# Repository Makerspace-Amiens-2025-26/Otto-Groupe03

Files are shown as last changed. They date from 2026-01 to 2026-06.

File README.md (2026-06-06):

# BMW-OTTO BOT

Template pour la création d'un repo type projet pour le MakerSpace. Doc gérée via le thème [Just-The-Docs](https://just-the-docs.com) en vanilla.

## Bienvenue sur Notre Projet

Ce repository est le cœur de notre projet. Ici, vous trouverez toutes les ressources nécessaires pour comprendre, utiliser et contribuer à notre projet.

### Contenu du Repository

- **Documentation :** Toutes les documentations techniques et guides d'utilisation sont disponibles dans le dossier `docs`. Voir le site de doc associé. 
- **project :** Toutes les sources de notre projet.

### Comment Utiliser ce Repository ?

- Pour commencer, consultez la documentation dans le dossier `docs`.
- Si vous souhaitez contribuer au projet, veuillez lire nos directives de contribution.

## Contribution

Nous accueillons et apprécions toute contribution. Si vous souhaitez contribuer, veuillez consulter notre guide de contribution pour connaître nos attentes et notre processus.

## Contact

Si vous avez des questions ou des suggestions, n'hésitez pas à nous contacter.

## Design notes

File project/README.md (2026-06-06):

# Les ressources du projet
Vous retrouverez les fichiers STL pour imprimer toutes les pièces nécessaires à la réalisation du robot

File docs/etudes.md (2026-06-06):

---
layout: default
nav_order: 4
title: Études et choix techniques
---

# Études et choix techniques

**CHÂSSIS**:

Pour aborder efficacement les différentes épreuves des Ottolympiades, on a dû faire des choix stratégiques. Il ne s'agissait pas seulement de donner un look "sport" à notre robot, mais d'utiliser l'univers mécanique de BMW pour optimiser ses performances réelles sur la piste.

Le design de notre OTTO-BMW a été pensé pour répondre aux contraintes physiques des épreuves de force et de vitesse :

* Abaissement du centre de gravité (Pour le Sumo) : Pour éviter que notre robot ne bascule facilement lors des duels sur le ring, nous avons choisi de placer la batterie le plus bas possible dans le corps du robot. De plus, nous avons augmenté le taux de remplissage des pieds afin d'alourdir la base et d'améliorer la stabilité.

* Adhérence des pneumatiques (Pour le Tir à la corde) : Les pieds en plastique PLA lisse d'origine glissaient sur la piste. En étudiant les solutions, nous avons décidé d'ajouter du papier de verre (découpée dans une chambre à air) sous les pieds du robot. Ce choix technique mime l'adhérence des pieds d'une vraie sportive et augmente notre force de traction de manière significative.

* L'Aileron M Performance (Utilité technique) : Au-delà du look, l'aileron arrière a été conçu avec un angle d'inclinaison spécifique pour servir de point d'ancrage solide et centré pour la corde lors de l'épreuve du Tir à la corde, évitant ainsi de désaxer le robot pendant l'effort.

**MOTORISATION** : 

Bien que la carte mère OTTO-MKS (ESP32-C3) soit imposée, nous avons optimisé l'utilisation des périphériques :

* Gestion des Servomoteurs SG90 : Ces moteurs fonctionnent avec des signaux PWM pour contrôler leur angle (0 à 180°). Pour la course de vitesse (Chrono Challenge), nous avons étudié les limites physiques des moteurs afin de trouver la fréquence maximale de balancement des jambes sans faire surchauffer les composants ni faire patiner le robot.

* Le Capteur Ultrason HC-SR04 (Les "Phares") : Intégré esthétiquement comme des optiques de phares BMW, ce capteur calcule la distance en mesurant le temps de retour d'une onde ultrason. Nous l'avons configuré pour deux fonctions clés : stopper le robot à 15 cm d'un mur (Course d'obstacles) et détecter la présence de l'adversaire à moins de 25 cm pour foncer dessus (Mode Sumo).

**LOGICIELS ET STRATEGIES** :

Le comportement du robot a été programmé sous l'IDE Arduino. Nous avons créé une véritable "cartographie moteur" adaptée à chaque épreuve :

* Le Mode "Sport" (Vitesse) : Pour le Chrono Challenge, nous avons développé une fonction de marche avec de grandes amplitudes de pas (angles des servos poussés au maximum) et un timing très court entre chaque pas pour obtenir une vitesse en ligne droite maximale.

* Pour le tir à la corde, nous avons programmé une fonction de marche arrière mais avec de petites amplitudes de pas pour que le robot soit le plus stable possible.

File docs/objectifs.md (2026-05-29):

---
layout: default
nav_order: 3
title: Objectifs du projet
---

# Introduction

Le projet OTTO-MKS, c'est le tout premier projet de robotique des premières années d'ingénieur à UniLaSalle Amiens.

Le but est simple : fabriquer et programmer un petit robot humanoïde en équipe. Nous sommes partis d'un modèle open-source ultra-connu (le robot Otto DIY), et le MakerSpace de l'école l'a amélioré pour créer l'OTTO-MKS, une version plus puissante connectée en Bluetooth et Wi-Fi.

Ce projet nous permet d'apprendre les bases du métier d'ingénieur :

* Mécanique : Modéliser et imprimer des pièces en 3D.

* Électronique : Connecter les moteurs et les capteurs.

* Programmation : Coder les mouvements et l'intelligence du robot.

Le point culminant du projet ? Les Ottolympiades ! Un grand tournoi où nos robots s'affrontent lors de la Journée des Projets dans des épreuves de course, de sumo et de tir à la corde.

Ce document présente notre travail, nos choix techniques et notre robot final pour la compétition.

## Contexte du Projet

Le projet OTTO-MKS est une version sur mesure ("made in UniLaSalle Amiens") du célèbre robot humanoïde open-source Otto DIY. Le robot original a été créé à l'origine pour enseigner les bases de la robotique, des STEM (Sciences, Technologie, Ingénierie, Mathématiques) et de la programmation.

Le MakerSpace d'Amiens a repris ce concept open-source pour l'adapter aux besoins spécifiques de ses étudiants et pour en faire le tout premier projet d'ingénierie des étudiants de première année. Pour cela, l'équipe du MakerSpace a conçu une version améliorée du robot :

* l'apprentissage par la pratique (Learning by doing), mêlant modélisation 3D (via OnShape), impression 3D des pièces mécaniques, assemblage de composants (servomoteurs, capteurs ultrason) et programmation (via l'IDE Arduino).

* Une carte électronique sur mesure (Otto-MKS) : Conçue au MakerSpace, elle intègre un microcontrôleur performant (ESP32-C3) offrant des capacités de communication sans fil (Bluetooth et Wi-Fi) permettant par exemple de piloter le robot avec un smartphone.

## Objectifs du Projet

Les objectifs du projet OTTO-MKS s'articulent autour de trois grands axes : pédagogique, technique et événementiel.

**Objectifs pédagogiques**:

On travaille par groupe de trois avec pour objectifs de :

* Découvrir la fabrication numérique : S'approprier les outils d'un MakerSpace, comprendre la modélisation 3D et gérer les contraintes de l'impression 3D.

* S'initier à la programmation embarquée : Programmer la logique du robot pour qu'il puisse marcher, détecter des obstacles et réagir à son environnement.

* Développer des compétences transversales : Travailler en équipe, documenter techniquement un projet (via un rapport ou un site web) et vulgariser leur travail à travers une vidéo de présentation professionnelle d'une minute.

**Objectifs techniques**:

* S'approprier et itérer : Au-delà du modèle de base fourni, l'objectif est de faire preuve de créativité. On doit modifier le code et le design du robot, y ajouter des fonctionnalités (bras articulés, écrans OLED, capteurs gyroscopiques, lumières).

* Fiabiliser et optimiser : Rendre le robot robuste mécaniquement et performant au niveau du code pour répondre à des contraintes physiques réelles.

* Améliorer ses compétences avec les logiciels et dans le code (Arduino)

**Objectifs événementiel**:

Le projet culmine chaque année lors de la Journée des Projets d'UniLaSalle Amiens, à travers un grand tournoi de robotique ludique et technique appelé les Ottolympiades (arbitré par l'association UniMakers). L'objectif ultime des étudiants est de préparer leur robot à valider l'homologation technique pour s'affronter dans 4 épreuves :

Chrono Challenge : Une course en ligne droite pour tester la vitesse pure.

Course d'obstacles : Un parcours d'agilité pour tester la détection de l'environnement.

Otto Sumo : Un duel sur un ring où le robot doit pousser son adversaire vers la sortie.

Tir à la corde : Une épreuve de force motrice par équipes de 3 robots.

# Existant

Notre projet s'appuie sur le robot bipède open-source Otto DIY, largement utilisé dans le domaine éducatif pour l'initiation aux STEM. Ce système existant est composé d'une structure imprimable en 3D, de 4 servomoteurs SG90 pour la locomotion, et d'un capteur ultrason HC-SR04 pour la détection d'obstacles.

Dans sa version standard, le contrôle est assuré par un microcontrôleur Arduino Nano. Bien que fonctionnelle pour un usage récréatif, cette configuration présente des limites techniques pour les objectifs des Ottolympiades : l'absence de connectivité sans fil native (Wi-Fi/Bluetooth) et la fragilité du câblage interne due à la superposition de cartes (Shield + Arduino).

C'est pour pallier ces limites que le MakerSpace d'UniLaSalle Amiens a développé la version OTTO-MKS, remplaçant cet existant par une carte électronique sur mesure intégrant une puce ESP32-C3.

# Cahier des Charges

**Dimensions**

Concernant les dimensions, Le robot devra faire au maximum :

* Largeur : 150 mm
* Longueur : 150 mm
* Hauteur : 200 mm

**Déplacement**

Pour les déplacements, le robot devra se déplacer en marchant.
L’interrupteur d’alimentation doit rester accessible en tout temps par l’arbitre afin d’arrêter le robot en cas de situation de danger pour lui-même, les autres robots, ou les éléments de jeu.

**Fabrication**

Le robot doit être fabriqué et programmé par les étudiant(e)s sans l’utilisation d’un kit du commerce. 
La modification est fortement encouragée mais ces derniers ne doivent pas pouvoir endommager le robot adverse. Les dispositifs présentant un danger sont évidemment proscrit.

**Mode de controle**

En fonction de l’épreuve, deux modes de fonctionnement pourront vous être demandés, précisés dans le règlement de l’épreuve :

* Mode autonome
Le robot doit être en mesure de réaliser l’épreuve sans aide extérieure ; il devra donc être programmé à l’avance pour jouer. Le signal de démarrage est propre à chaque épreuve et est spécifié dans son règlement.

* Mode télécommandé
Vous devrez programmer une solution de contrôle à distance, par exemple grâce à l’application RemoteXY.

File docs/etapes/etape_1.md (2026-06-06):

---
layout: default
title: Préparation des Matériaux
parent: Etapes de fabrication
nav_order: 1
---

# Préparation des Matériaux

Cette section décrit la première étape du processus de fabrication : la préparation des matériaux.

## Liste des Matériaux

- L'ensemble du dossier STL imprimé en 3d (PLA)
- Un set de tournevisse
- Du papier de verre + gros grain possible

## Procédure de Préparation

1. **Nettoyage** : Nettoyez les impressions enn retirant les supports et bavure
2. **Découpe** : Découpez le papier de verre a la taile des pieds en laissant une bande vide de 1cm a l'edxterieur du pied

## Conseils de Sécurité

- Portez toujours l'équipement de protection individuelle.
- Suivez les instructions de sécurité des outils utilisés.

---

Une fois cette étape terminée, passez à l'[Assemblage](/assemblage).

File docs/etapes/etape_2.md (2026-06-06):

---
layout: default
title: Assemblage
parent: Etapes de fabrication
nav_order: 2
---

# Assemblage

Après l’impression des pièces en 3D, l’étape suivante est l’assemblage du robot Otto.  
Cette étape permet de monter les servomoteurs, les jambes, les pieds, la tête, la carte électronique, le capteur ultrason et la batterie.

Schéma général du robot Otto

## Objectif

L’objectif de cette partie est d’obtenir un robot entièrement assemblé, prêt à être programmé et testé.

Un bon assemblage est important car un mauvais positionnement des servomoteurs peut empêcher le robot de marcher correctement.

## Matériel nécessaire

Avant de commencer, il faut vérifier que tout le matériel est présent.

Matériel nécessaire

Il faut notamment :

- les pièces imprimées en 3D ;
- la tête ;
- le corps ;
- les deux jambes ;
- les deux pieds ;
- 4 servomoteurs SG90 ;
- les palonniers des servomoteurs ;
- le capteur ultrason HC-SR04 ;
- la carte électronique Otto-MKS ;
- une batterie 9V ;
- une cosse de batterie ;
- un câble USB ;
- un tournevis ;
- les vis nécessaires.

## Précautions avant l’assemblage

Avant de commencer, il faut prendre son temps et vérifier chaque étape.

> ⚠️ Les servomoteurs sont fragiles.  
> Il ne faut pas forcer leur rotation à la main, car cela peut abîmer les engrenages internes.

Il faut aussi faire attention au type de vis utilisé.  
Une vis trop longue ou mal placée peut endommager une pièce ou un servomoteur.

## Étapes d’assemblage

### Étape 1 - Assemblage du corps

Insérez les servomoteurs dans la pièce `Body`, aux emplacements prévus.

Les servomoteurs doivent être placés correctement et bien alignés.

<!-- Image possible :
![Assemblage du corps](images/assemblage-corps.png)
-->

### Étape 2 - Vissage des servomoteurs

Vissez les servomoteurs dans le corps du robot.

> ⚠️ Vérifiez le type de vis avant de visser.

Il ne faut pas trop serrer afin de ne pas abîmer le plastique imprimé en 3D.

### Étape 3 - Assemblage des palonniers

Découpez deux palonniers comme indiqué dans le tutoriel.

Insérez ensuite les palonniers dans les pièces `Leg`.

Les palonniers doivent être enfoncés jusqu’au fond de leur emplacement.

### Étape 4 - Positionnement des servomoteurs à 90°

Avant de fixer les jambes, il faut positionner les servomoteurs à 90°.

Pour cela, on utilise le programme Arduino réalisé précédemment pour mettre les servomoteurs en position neutre.

Cette étape est très importante, car elle permet d’avoir des jambes bien droites.

### Étape 5 - Assemblage des jambes

Branchez les deux servomoteurs sur la carte électronique.

Lancez le programme permettant de les positionner à 90°.

Insérez ensuite les jambes sur l’axe des servomoteurs dans la bonne position.

Après cela, débranchez les servomoteurs et vérifiez que les butées sont bien placées autour de la position neutre.

### Étape 6 - Vissage des jambes

Vissez les jambes sur les axes des servomoteurs.

> ⚠️ Vérifiez le type de vis avant de visser.

Les jambes doivent être bien fixées, mais il ne faut pas forcer.

### Étape 7 - Assemblage des palonniers des pieds

Insérez les palonniers dans les pièces `Left_Foot` et `Right_Foot`.

Ils doivent être enfoncés jusqu’à la butée.

### Étape 8 - Vissage des palonniers des pieds

Vissez fermement les palonniers dans les pieds.

> ⚠️ Vérifiez le type de vis utilisé.

Cette étape permet de créer une liaison solide entre les pieds et les servomoteurs.

### Étape 9 - Assemblage des servomoteurs des pieds

Branchez les deux servomoteurs des pieds sur la carte électronique.

Lancez à nouveau le programme de positionnement à 90°.

Insérez ensuite les servomoteurs dans les pièces `Foot` en respectant leur orientation.

Vérifiez que les butées sont bien à 90° de chaque côté de la position neutre.

### Étape 10 - Vissage des servomoteurs des pieds

Vissez les axes des servomoteurs des pieds.

> ⚠️ Vérifiez le type de vis avant de visser.

Il faut aussi faire attention à ne pas tirer sur les câbles.

### Étape 11 - Assemblage des pieds

Insérez les pieds dans les emplacements prévus sur les jambes.

Faites passer les fils des servomoteurs dans les trous de la pièce `Body`.

Les câbles doivent pouvoir remonter proprement à l’intérieur du robot.

### Étape 12 - Vissage des pieds

Vissez la deuxième vis des servomoteurs.

Les pieds doivent être bien fixés aux jambes.

### Étape 13 - Assemblage du capteur ultrason

Glissez le capteur ultrason HC-SR04 dans la pièce `Head`.

Il faut respecter le sens indiqué pour que les deux capteurs soient visibles à l’avant du robot.

> ⚠️ Les grilles avant du capteur ultrason sont fragiles.  
> Il faut éviter d’appuyer dessus.

### Étape 14 - Préparation de la carte électronique

Dévissez la rondelle et l’écrou du bouton de la carte électronique.

Conservez-les, car ils seront réutilisés pour fixer la carte dans la tête du robot.

### Étape 15 - Installation de la carte électronique

Insérez délicatement la carte électronique dans la pièce `Head`.

Vérifiez que les broches du capteur ultrason s’insèrent correctement dans le connecteur de la carte.

Le bouton doit être enfoncé jusqu’à la butée.

### Étape 16 - Assemblage de la tête

Remettez la rondelle, puis revissez l’écrou du bouton.

> ⚠️ L’ergot de la rondelle doit s’insérer dans l’un des trous prévus.

Cela permet de maintenir correctement la carte électronique dans la tête.

### Étape 17 - Installation de la batterie

Fixez la cosse 9V sur la batterie.

> ⚠️ La carte ne doit surtout pas être branchée à l’envers, sinon elle peut être endommagée.

Insérez ensuite la batterie dans son emplacement, avec les câbles orientés vers le haut.

### Étape 18 - Câblage

Branchez les servomoteurs sur la carte électronique en respectant l’ordre prévu.

Il faut également vérifier le sens des connecteurs :

- fil marron : masse ;
- fil rouge : +5V ;
- fil jaune : signal.

Branchez ensuite la batterie sur le connecteur d’alimentation.

Utilisez une bande de velcro pour organiser les câbles proprement à l’intérieur du robot.

### Étape 19 - Assemblage final

Refermez la tête sur le corps.

Appuyez légèrement sur les côtés pour faciliter l’emboîtement.

> ⚠️ Vérifiez qu’aucun câble n’est coincé entre la tête et le corps.

## Vérifications à effectuer

Avant de tester le robot, il faut vérifier que :

- les servomoteurs sont bien vissés ;
- les jambes sont dans le bon sens ;
- les pieds sont bien alignés ;
- les câbles ne sont pas coincés ;
- les connecteurs sont branchés dans le bon sens ;
- le capteur ultrason est bien placé ;
- la batterie est bien connectée ;
- la tête se ferme correctement ;
- aucune pièce ne bloque le mouvement.

## Problèmes communs et solutions

### Le robot marche de travers

Cela peut venir d’un mauvais centrage des servomoteurs.

Il faut relancer le programme de positionnement à 90°, puis replacer les jambes ou les pieds correctement.
Si le problème persiste il faut ajuster les trims dans le code 

### Les pièces ne s’emboîtent pas correctement

Les pièces imprimées en 3D peuvent parfois avoir de légères différences de dimensions.

Solutions possibles :

- vérifier l’orientation des pièces ;
- poncer légèrement les zones qui bloquent ;
- vérifier les dimensions dans le slicer ;
- modifier légèrement l’échelle des pièces dans le slicer.

### Un servomoteur ne bouge pas

Il faut vérifier :

- le branchement du servomoteur ;
- le sens du connecteur ;
- le câble ;
- le programme Arduino ;
- l’alimentation de la carte.

### La tête ne ferme pas

Cela arrive souvent si les câbles sont mal rangés.

Il faut replacer les câbles avec le velcro et vérifier qu’ils ne sont pas coincés.

### Le robot ne s’allume pas

Il faut vérifier :

- la batterie ;
- la cosse 9V ;
- le connecteur d’alimentation ;
- le sens de branchement ;
- la carte électronique.

## Conclusion

Une fois l’assemblage terminé, le robot Otto est prêt à être programmé et testé.

Cette étape doit être réalisée avec soin, car le positionnement des servomoteurs et le rangement des câbles influencent directement le fonctionnement du robot.

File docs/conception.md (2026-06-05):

---
layout: default
nav_order: 5
title: Conception et prototypage
---

# Conception et prototypage

Pour nous démarquer lors des épreuves et des Ottolympiades, notre équipe a choisi de donner à notre robot un design inspiré de l'univers automobile, et plus particulièrement de la marque BMW. L'objectif était de créer un robot au look agressif et "sport", tout en intégrant des éléments aérodynamiques utiles pour la compétition.

**Personnalisation et Identité BMW** :

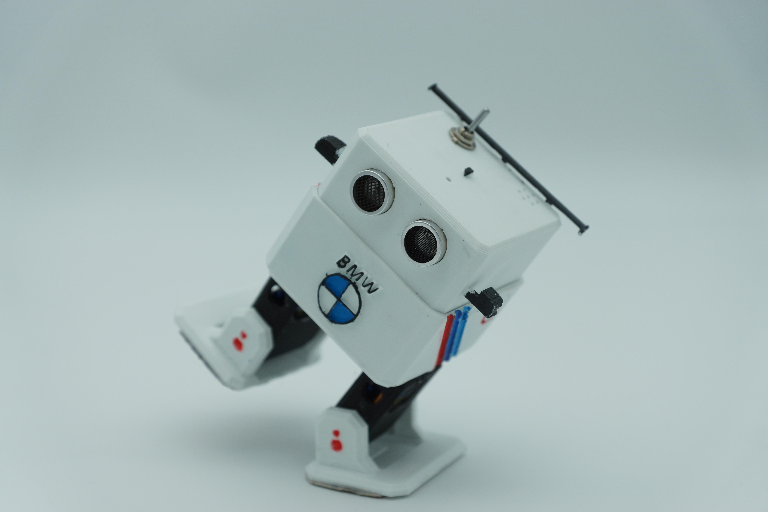
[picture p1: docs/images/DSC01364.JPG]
Image robot


Comme l'illustre la figure ci-dessus, notre conception finale intègre des éléments clés qui rappellent directement l'identité visuelle de la marque :

* Face avant : Le logo BMW ainsi que l'inscription ont été intégrés en relief directement sur le bouclier avant de la carrosserie, centré sous le capteur à ultrasons.

* Rétroviseurs et Bandes Sport : Deux rétroviseurs latéraux noirs ont été fixés sur la tête. De plus, les trois célèbres bandes de couleur de la division sportive (Bleu clair, Bleu foncé, Rouge) ont été peintes/intégrées sur le flanc droit du châssis.

* L'Aileron arrière et Interrupteur : Un aileron fin de type "lame" noire a été conçu et fixé à l'arrière supérieur de la tête. Juste devant, un interrupteur à levier métallique robuste a été implanté sur le sommet de la coque pour permettre une mise sous tension rapide du système avant le départ des courses.

**Prototypage et Fabrication** :

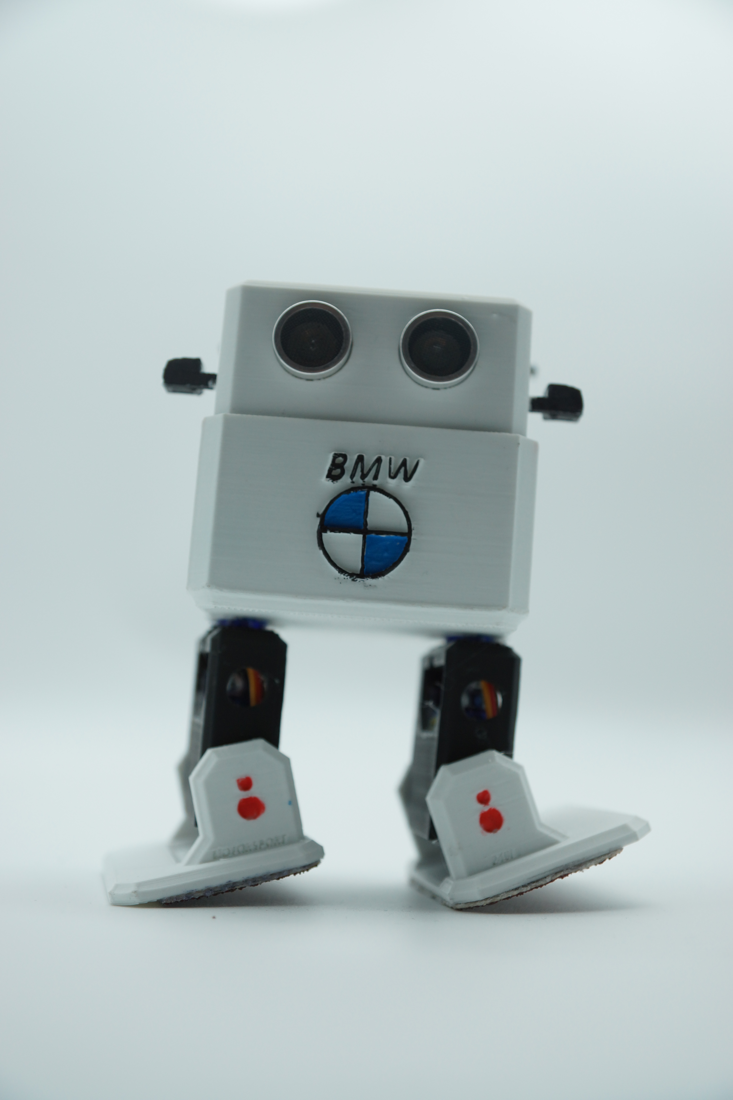
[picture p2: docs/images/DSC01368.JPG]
Image robot
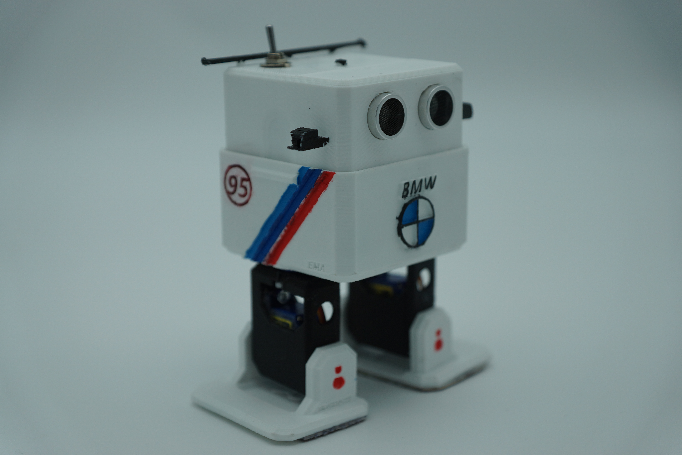
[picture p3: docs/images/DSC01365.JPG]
Image robot
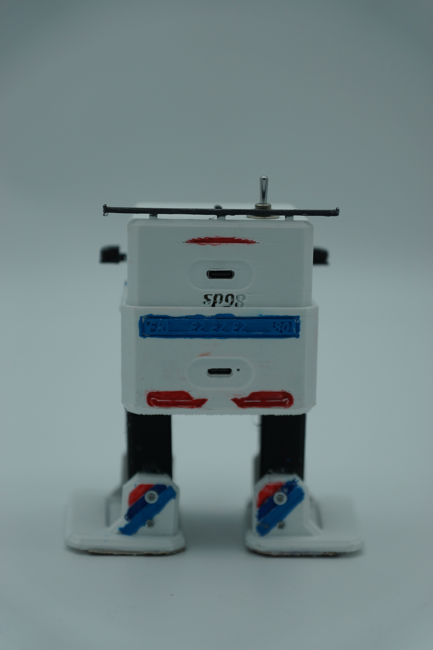
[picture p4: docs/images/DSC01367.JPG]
Image robot
   

La phase d'assemblage et de finition de notre modèle OTTO-BMW a nécessité plusieurs choix de fabrication précis au MakerSpace :

* Gestion des couleurs à l'impression : Pour obtenir ce rendu bicolore, la carrosserie principale et les pieds ont été imprimés en PLA blanc, offrant un contraste parfait avec les éléments mécaniques internes (servomoteurs noirs) et les accessoires (aileron, jambes, rétroviseurs imprimés en noir).

* Ajustement des détails visuels : Les détails du logo et des jantes de fixation des chevilles (marquées de points rouges) ont été finalisés à la main pour accentuer le look "compétition" du robot.

* Validation de la garde au sol : La photo montre le robot en pleine phase de test de balancement (marche sur un pied). On constate que le profil bas du bouclier avant ne gêne pas l'amplitude du mouvement et assure une excellente stabilité dynamique. Les patins d'adhérence ajoutés sous les semelles sont également visibles et valident nos choix techniques pour l'épreuve de traction.

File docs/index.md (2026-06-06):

---
layout: home
nav_order: 1
title: Accueil
permalink: /
---

# Bienvenue sur notre documentation

Bienvenue dans la documentation du projet OTTO-MKS. Ce site a pour but de fournir toutes les informations nécessaires pour comprendre, utiliser et reproduire efficacement notre projet.

# Sommaire :

**Introduction** :

Présentation globale du projet, contexte du MakerSpace d'Amiens et présentation de votre équipe (Le projet "OTTO-BMW").

* I. Contexte et Analyse de l’Existant

a) Le projet open-source Otto DIY standard

b) Limites techniques du modèle d'origine 

c) La transition vers la version OTTO-MKS

* II. Études et Choix Techniques

a) Objectifs de performance pour les Ottolympiades

b) Choix mécaniques et aérodynamiques 

c) Choix électroniques 

d) Stratégies logicielles et modes de conduite 

* III. Conception du Système 

a) Modélisation 3D sur OnShape 

b) Architecture matérielle et connectivité 

c) Logigrammes et algorithmes de fonctionnement 

* IV. Prototypage, Fabrication et Assemblage

a) Paramètres d'impression 3D au MakerSpace

b) Assemblage mécanique et intégration sur la carte OTTO-MKS

c) Calibrage des servomoteurs et finitions esthétiques 

d) Itérations et corrections après les premiers tests 

* V. Retours d'Expérience et Résultats 

a) Déroulement des épreuves 

b) Analyse des performances du robot OTTO-BMW

c) Présentation de la vidéo du projet 

[Notre projet sur Onshape](https://cad.onshape.com/documents/b19b26d3fabd52bd86858b2e/w/a6f33b540fe525643befe4be/e/70175bb2256358d0cd1cc287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){: .btn .btn-primary .fs-5 .mb-4 .mb-md-0 .mr-2 }
[Notre repo GitHub](https://github.com/Makerspace-Amiens-2025-26/Otto-Groupe03/){: .btn .fs-5 .mb-4 .mb-md-0 }

<iframe height="600" width="100%" src="https://modelembedder.net/embed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" frameborder="0"></iframe>

## À propos du Projet

Ce projet a pour but de concevoir, fabriquer et programmer le robot humanoïde bipède OTTO-BMW, une version personnalisée et améliorée du robot open-source Otto DIY. Conçu dans le cadre du premier projet d’ingénierie d'UniLaSalle Amiens, il est destiné aux étudiants pour leur permettre d'acquérir des compétences pratiques en mécanique (CAO/impression 3D), en électronique et en programmation embarquée.

Le projet cherche à résoudre plusieurs problèmes concrets :

* Sur le plan technique : Il vise à s'affranchir des limites du robot d'origine (fragilité des câbles, manque de puissance et de connectivité sans fil) grâce à l'utilisation d'une carte électronique sur mesure (OTTO-MKS à base d'ESP32-C3).

* Sur le plan de la performance : Le but ultime est de concevoir un robot robuste, rapide, stable et intelligent, capable de remporter le tournoi des Ottolympiades (épreuves de vitesse, d'évitement d'obstacles, de sumo et de tir à la corde).

## Poster

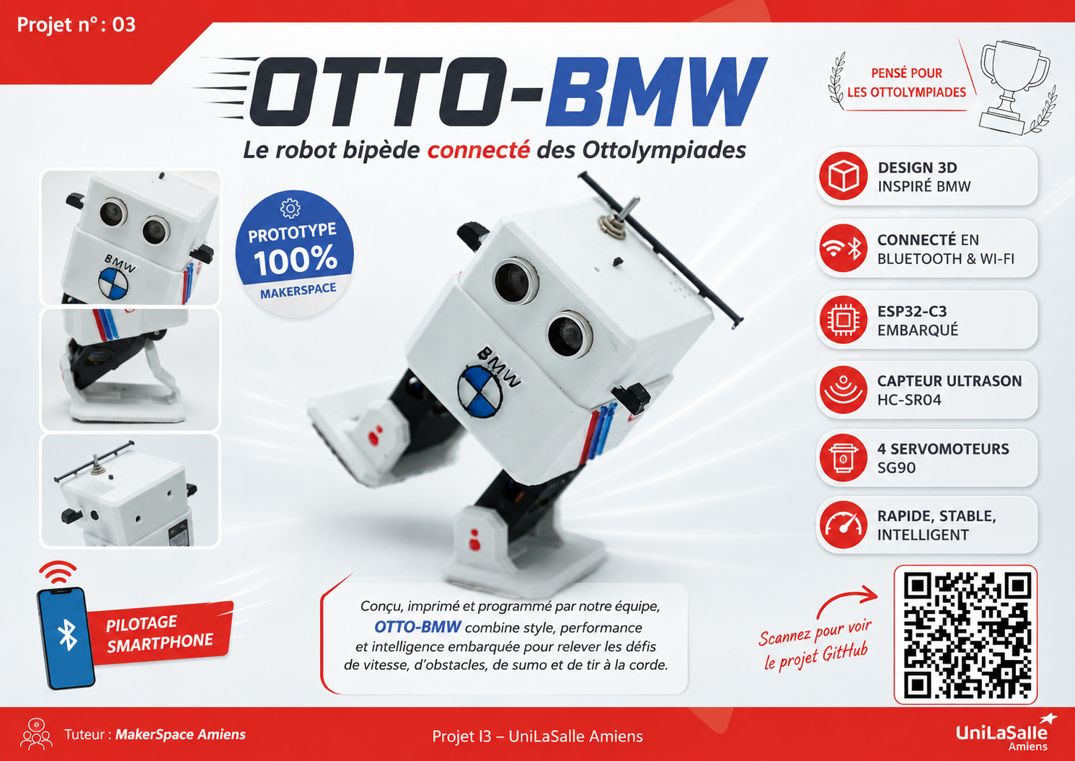
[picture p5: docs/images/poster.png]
Poster projet


## Vidéo

<video src="images/video.mp4" controls title="Title"  style="width: 100%;"></video>

---

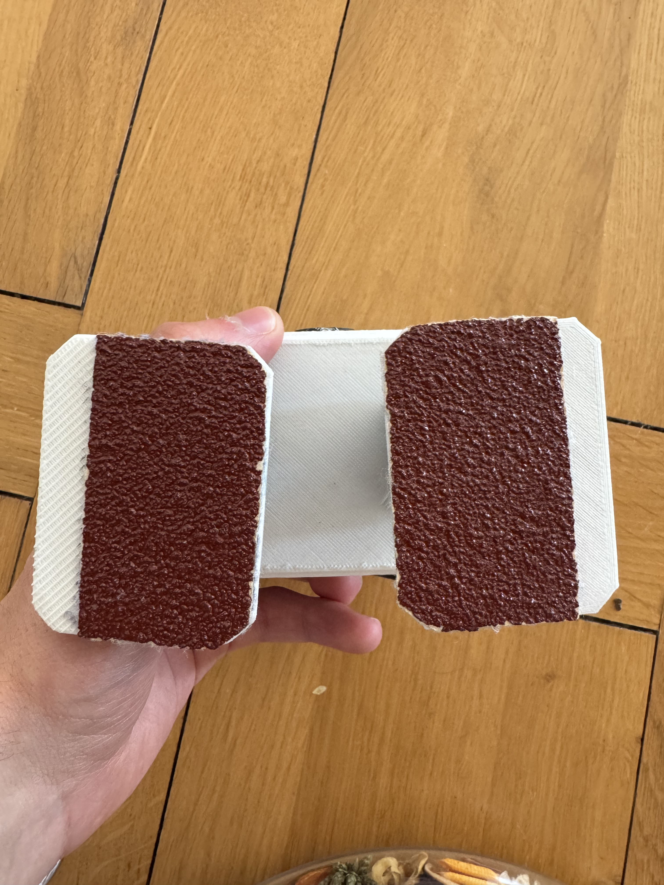
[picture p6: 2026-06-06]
docs/images/pied.jpeg

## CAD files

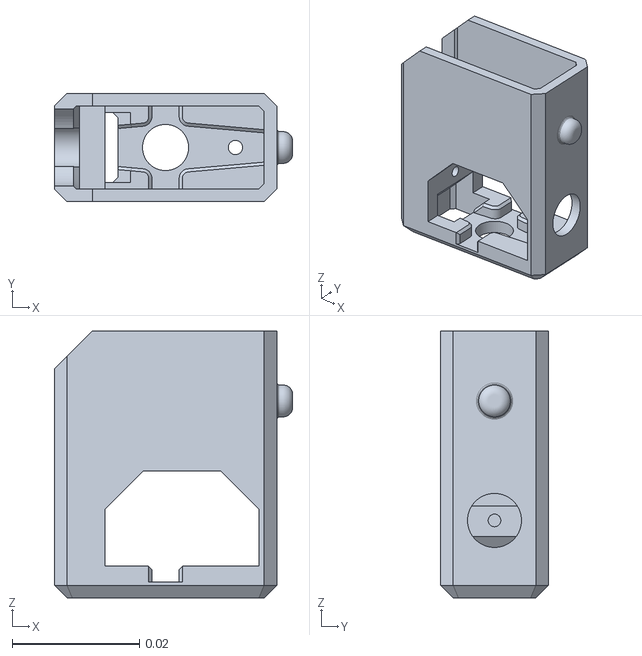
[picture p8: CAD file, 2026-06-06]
project/STL/Leg.stl
0.0375 x 0.017 x 0.042

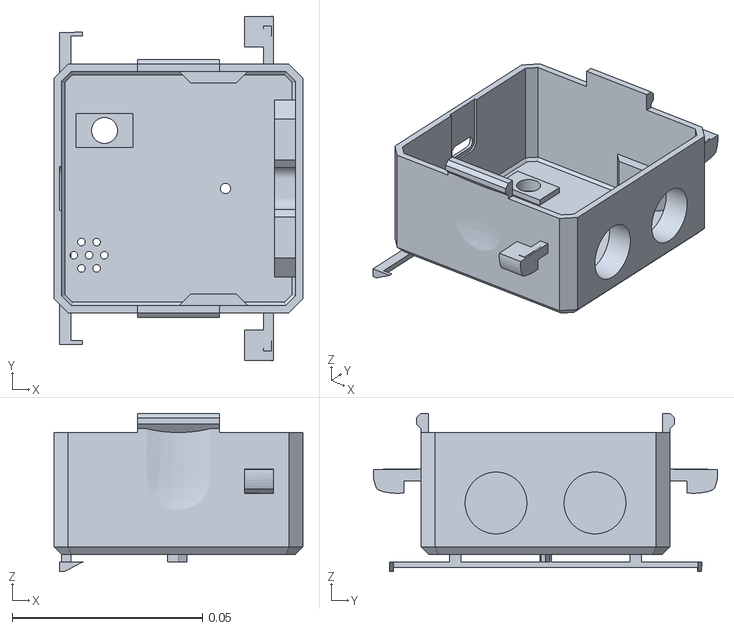
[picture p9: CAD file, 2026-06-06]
project/STL/Head.stl
0.0654 x 0.0905 x 0.0415

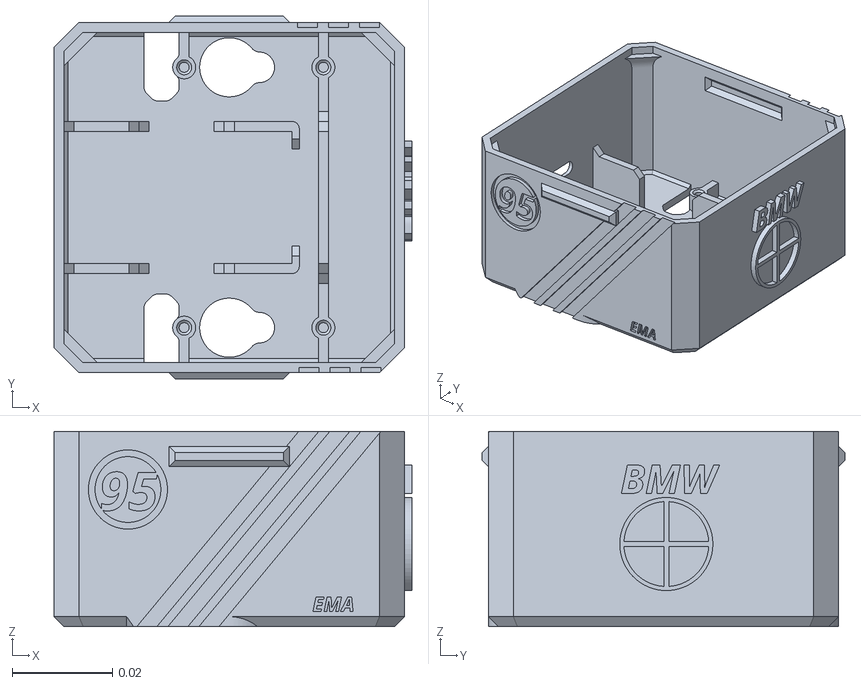
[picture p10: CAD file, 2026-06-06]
project/STL/Body.stl
0.0715 x 0.0724 x 0.039

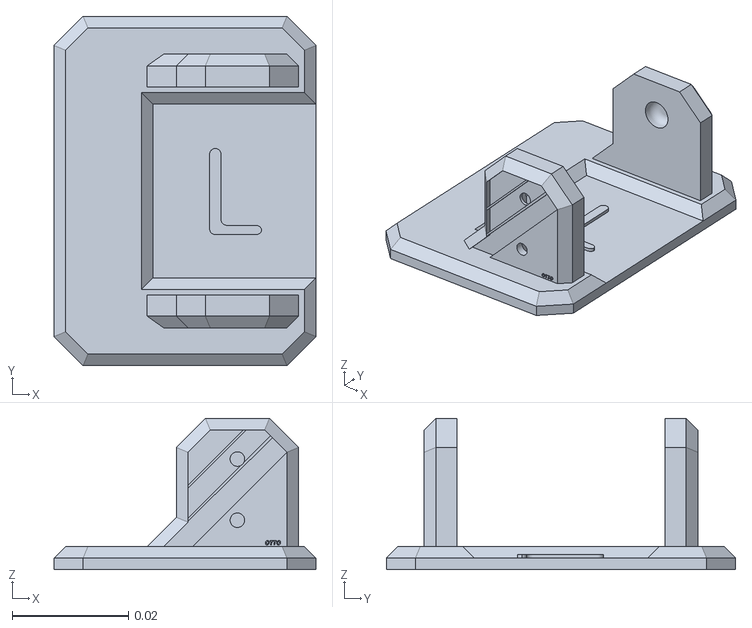
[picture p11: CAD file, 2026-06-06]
project/STL/Left_Foot.stl
0.045 x 0.06 x 0.026

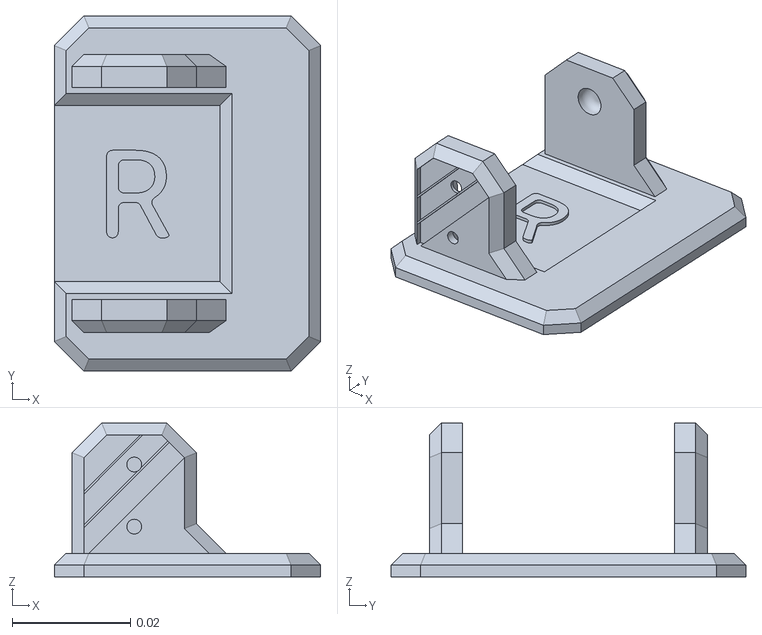
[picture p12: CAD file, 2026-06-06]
project/STL/Right_Foot.stl
0.045 x 0.06 x 0.026

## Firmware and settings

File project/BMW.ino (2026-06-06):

// RemoteXY select connection mode and include library
#define REMOTEXY__DEBUGLOG  
#define REMOTEXY_MODE__ESP32CORE_BLE

// RemoteXY connection settings
#include <BLEDevice.h>
#include <ESP32Servo.h>

// RemoteXY connection settings
#define REMOTEXY_BLUETOOTH_NAME "BMW-BOT"
#define REMOTEXY_ACCESS_PASSWORD "1234"

#include <RemoteXY.h>

#pragma pack(push, 1)  
uint8_t const PROGMEM RemoteXY_CONF_PROGMEM[] =   // 80 bytes V19
  { 255,5,0,0,0,73,0,19,0,0,0,77,105,110,105,116,116,111,0,6,
  2,106,200,200,84,1,1,4,0,3,30,7,16,44,37,24,38,7,134,2,
  26,5,32,60,60,60,121,15,57,57,32,2,26,31,1,6,120,24,24,61,
  41,24,24,0,2,31,0,1,48,131,24,24,28,41,24,24,0,2,31,0 };
 
// this structure defines all the variables and events of your control interface
struct {

    // input variables
  uint8_t selectorSwitch_01;
  int8_t joystick_01_x;
  int8_t joystick_01_y; 
  uint8_t button_01; 
  uint8_t button_02;  

  uint8_t connect_flag;

} RemoteXY;  
#pragma pack(pop)

#define PIN_JAMBE_G D7
#define PIN_PIED_G  D8
#define PIN_JAMBE_D D10
#define PIN_PIED_D  D9
#define BUZZER_PIN  D0 

int vitesseMouvement = 3; 
int centre = 90;

int trimJG = -1, trimJD = -2, trimPG = -3, trimPD = 0;

Servo jambeG, jambeD, piedG, piedD;

// --- DÉFINITIONS MUSIQUE (MARCHE IMPÉRIALE) ---
#define NOTE_A3 220
#define NOTE_F3 175
#define NOTE_C4 262
#define NOTE_A4 440
#define NOTE_F4 349
#define NOTE_C5 523
#define REST    0

int imperialMarch[][2] = {
  {NOTE_A3, 500}, {NOTE_A3, 500}, {NOTE_A3, 500}, {NOTE_F3, 350}, {NOTE_C4, 150}, {NOTE_A3, 500},
  {NOTE_F3, 350}, {NOTE_C4, 150}, {NOTE_A3, 650}, {REST, 500},
  {NOTE_A4, 500}, {NOTE_A4, 500}, {NOTE_A4, 500}, {NOTE_F4, 349}, {NOTE_C5, 150}, {NOTE_A4, 500},
  {NOTE_F4, 349}, {NOTE_C5, 150}, {NOTE_A4, 650}
};

void playMusic() {
  int totalNotes = sizeof(imperialMarch) / sizeof(imperialMarch[0]);
  for (int i = 0; i < totalNotes; i++) {
    int freq = imperialMarch[i][0];
    int duration = imperialMarch[i][1];
    if (freq == REST) {
      noTone(BUZZER_PIN);
    } else {
      tone(BUZZER_PIN, freq, duration);
    }
    RemoteXYEngine.delay(duration * 1.2);
    noTone(BUZZER_PIN);
  }
}


void klaxon() {
  // Un double coup de klaxon strident (aigu)
  tone(BUZZER_PIN, 880, 150);
  delay(200);
  noTone(BUZZER_PIN);
  
  tone(BUZZER_PIN, 880, 150);
  delay(150);
  noTone(BUZZER_PIN);
}

// --- FONCTION BIP MARCHE ARRIÈRE (NON-BLOQUANTE) ---
unsigned long precedentMillisBip = 0;
bool etatBip = false;

void gererBipRecul(bool actif) {
  if (!actif) {
    noTone(BUZZER_PIN);
    etatBip = false;
    return;
  }

  unsigned long actuelMillis = millis();
  // Alterne toutes les 350 ms pour faire "BIP... (silence)... BIP..."
  if (actuelMillis - precedentMillisBip >= 350) {
    precedentMillisBip = actuelMillis;
    etatBip = !etatBip;
    
    if (etatBip) {
      tone(BUZZER_PIN, 1000); // Bip aigu à 1000 Hz
    } else {
      noTone(BUZZER_PIN);
    }
  }
}

void homePosition() {
  jambeG.write(centre + trimJG);
  jambeD.write(centre + trimJD);
  piedG.write(centre + trimPG);
  piedD.write(centre + trimPD);
}

void updateSpeedAndCheck() {
  RemoteXYEngine.handler(); 
  int maxInput = max(abs(RemoteXY.joystick_01_y), abs(RemoteXY.joystick_01_x));
  vitesseMouvement = map(maxInput, 0, 100, 10, 2); 

  // On vérifie le klaxon même pendant qu'Otto marche !
  if (RemoteXY.button_01 == 1) {
    klaxon();
  }
}

void moveSlow(Servo &s, int target) {
  int currentPos = s.read();
  int direction = (currentPos < target) ? 1 : -1;

  for (int i = currentPos; i != target + direction; i += direction) {
    updateSpeedAndCheck();
    s.write(i);
    RemoteXYEngine.delay(vitesseMouvement);
  }
}

// Marche Avant
void walk(int angleGauche, int angleDroite) {
  gererBipRecul(false);

  moveSlow(piedG, centre - 23);
  moveSlow(piedD, centre - 45);

  moveSlow(jambeG, centre + angleGauche);
  moveSlow(piedG, centre + trimPG);
  moveSlow(piedD, centre + trimPD);
  moveSlow(jambeG, centre + trimJG);

  moveSlow(piedD, centre + 20);
  moveSlow(piedG, centre + 40);
  moveSlow(jambeD, centre - angleDroite);

  moveSlow(piedD, centre + trimPD);
  moveSlow(piedG, centre + trimPG);
  moveSlow(jambeD, centre + trimJD);
}

// Marche Arrière
void backward(int angleGauche, int angleDroite) {
  gererBipRecul(true);

  moveSlow(piedD, centre + 42);
  moveSlow(piedG, centre + 20);

  gererBipRecul(true);
  moveSlow(jambeD, centre + angleDroite);
  moveSlow(piedD, centre + trimPD);
  moveSlow(piedG, centre + trimPG);
  moveSlow(jambeD, centre + trimJD);

  gererBipRecul(true);
  moveSlow(piedD, centre - 42);
  moveSlow(piedG, centre - 20);

  gererBipRecul(true);
  moveSlow(jambeG, centre - angleGauche);
  moveSlow(piedD, centre + trimPD);
  moveSlow(piedG, centre + trimPG);
  moveSlow(jambeG, centre + trimJG);
}

// Pas chassé à DROITE
void sidestepRight() {
  gererBipRecul(false);

  moveSlow(piedG, centre + trimPG - 25);
  moveSlow(piedD, centre + trimPD - 25);
  moveSlow(jambeD, centre + trimJD - 30);

  moveSlow(piedG, centre + trimPG);
  moveSlow(piedD, centre + trimPD);

  moveSlow(piedG, centre + trimPG + 25);
  moveSlow(piedD, centre + trimPD + 25);
  moveSlow(jambeG, centre + trimJG - 30);

  moveSlow(jambeG, centre + trimJG);
  moveSlow(jambeD, centre + trimJD);
  moveSlow(piedG, centre + trimPG);
  moveSlow(piedD, centre + trimPD);
}

// Pas chassé à GAUCHE
void sidestepLeft() {
  gererBipRecul(false);

  moveSlow(piedG, centre + trimPG + 25);
  moveSlow(piedD, centre + trimPD + 25);
  moveSlow(jambeG, centre + trimJG + 30);

  moveSlow(piedG, centre + trimPG);
  moveSlow(piedD, centre + trimPD);

  moveSlow(piedG, centre + trimPG - 25);
  moveSlow(piedD, centre + trimPD - 25);
  moveSlow(jambeD, centre + trimJD + 30);

  moveSlow(jambeG, centre + trimJG);
  moveSlow(jambeD, centre + trimJD);
  moveSlow(piedG, centre + trimPG);
  moveSlow(piedD, centre + trimPD);
}
void setup() {
  RemoteXY_Init();
  Serial.begin(115200);
  pinMode(BUZZER_PIN, OUTPUT);

  jambeG.attach(PIN_JAMBE_G);
  piedG.attach(PIN_PIED_G);
  jambeD.attach(PIN_JAMBE_D);
  piedD.attach(PIN_PIED_D);
  
  homePosition();


  playMusic(); 
}

void loop() { 
  updateSpeedAndCheck();   

  int correctionLigneDroite = 10; 
  int angleJG = 55; 
  int angleJD = 55 - correctionLigneDroite; 

  // Actionneur principal
  if (abs(RemoteXY.joystick_01_y) >= abs(RemoteXY.joystick_01_x) && abs(RemoteXY.joystick_01_y) > 15) {
    if (RemoteXY.joystick_01_x > 15) { 
      angleJG = map(RemoteXY.joystick_01_x, 15, 100, 55, 15);
    } 
    else if (RemoteXY.joystick_01_x < -15) { 
      angleJD = map(RemoteXY.joystick_01_x, -15, -100, (55 - correctionLigneDroite), 15);
    }

    if (RemoteXY.joystick_01_y > 15) {
      walk(angleJG, angleJD);
    } 
    else {
      backward(angleJG, angleJD);
    }
  } 
  else if (abs(RemoteXY.joystick_01_x) > 40) {
    if (RemoteXY.joystick_01_x > 40) {
      sidestepRight();
    } else {
      sidestepLeft();
    }
  } 
  else {
    gererBipRecul(false); // Coupe le son si on s'arrête
    homePosition();
  }
}

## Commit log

2026-06-02 Expand documentation on robot design and strategies
    Added detailed technical choices for the robot's design, motorization, and software strategies, enhancing the documentation of the project.
2026-06-05 Insert robot image in objectifs.md
    Added an image of the robot to the objectives document.
2026-06-05 Mise à jour de la conception avec analyse du prototype
    Ajout d'une section sur l'analyse du prototype réel et des finitions, ainsi que des détails sur la gestion des couleurs, l'ajustement des détails visuels et la validation de la garde au sol.
2026-06-06 fichier 3d
    [Body.stl, Head.stl, Left_Foot.stl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]
2026-06-06 Revise materials list in etape_1.md
    Updated the materials list for the manufacturing process.
2026-06-06 Add description for STL files in README
    Added a description of the STL files for the robot.
2026-06-06 Documenter l'assemblage du robot Otto
    Ajout de détails sur l'assemblage du robot Otto, y compris les étapes, le matériel nécessaire et les précautions à prendre. Mise à jour des vérifications et des problèmes communs.
2026-06-06 Enhance assembly documentation for Otto robot
    Added detailed assembly instructions for the Otto robot, including objectives, materials needed, precautions, and assembly steps.
2026-06-06 Revise styling and enhance assembly documentation
    Updated styling and added assembly instructions for the robot Otto.
2026-06-06 Revise assembly instructions and update images
2026-06-06 Revise assembly instructions for Otto robot
    Updated the assembly instructions for the Otto robot, improving clarity and consistency throughout the document. Adjusted wording and formatting for better readability.
2026-06-06 Fix formatting in etape_1.md materials list
